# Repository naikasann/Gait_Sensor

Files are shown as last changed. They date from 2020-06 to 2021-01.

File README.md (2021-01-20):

# Gait_Sensor

歩容センサーの研究用リポジトリ
アーカイブ目的で運用している。

---

## 概要

健康促進などのための歩容を計測するデバイスを作成している。
その研究データを貯蓄するリポジトリ。

---

## ファイル構成

詳細は各フォルダー内に記載する。

- Gaitsensor --- 歩容センサーの計測を行うプログラム。BLE通信で左右の足のデータを計測し、Bluetooth classicで表示する。LPWA通信する機能などを追加予定。
- GaitSensor_Blynkdemo --- 歩容センサーのデモプログラム。スマートフォンアプリの[Blynk](https://blynk.io/)を用いて歩容の情報を表示するプログラムになっている。バグあり。
- GaitSensor_pintest --- 歩容センサーの動作確認をすることができるプログラム。
- GaitSensor_resource --- 歩容センサーを構築するための3Dプリンターのモデルをためておく場所
- LAWA --- LPWA通信(SensewayのLoRaWAN, Sigfox)をすることができるプログラム。

---

## 使用しているハードウェア

なるべく持続的に購入することができるリンクを添付しておく。

### ```マイコン部分```

- [ATOM Lite](https://www.switch-science.com/catalog/6262/)

今後はnRF52などのマイコンでの動作を行う予定。

### ```電池系```

- [リチウムイオンポリマー電池(3.7V、300mAh) DTP502035(PHR)](https://www.marutsu.co.jp/pc/i/1559500/)
- [LiPo Charger Plus(LiPo充電器) PRT-15217](https://www.marutsu.co.jp/pc/i/1558373/)

今後はボタン電池稼働を目指している。

### ```センサー```

センサーはetextileセンサーを用いている。

## 参加した学会

おそらく閲覧するにはいろいろ手続きが必要。

1. [CiNii 論文 -  インソール型歩容センサーのための歩容解析システムの構築](https://ci.nii.ac.jp/naid/170000182936/)
2. [研究会 開催プログラム - 2020-05-HIP-HCS-HI-SIGCE](https://www.ieice.org/ken/program/index.php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)

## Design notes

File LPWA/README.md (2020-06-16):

# LPWA

LPWAのテスト用プログラム置き場

---

## LoRa

LoRaのためのテストプログラム
温度と光センサーの値をLoRa通信する。
SenseWay Mission Connectのサービスを利用したもの。

### LoRa構成

``` 構成.
Sensor => Arduino(LoRaWAN Shield for Arduino付) =(LoRaWAN)> SenseWay Mission Connect
```

### 参考

1. 使用したサービス - [サービス概要 ｜ センスウェイ株式会社](https://www.senseway.net/service/network-service/)
2. 使用したデバイス - [LoRaWAN Shield for Arduino ｜ SenseWay Mission Connect LoRaWAN 対応製品ガイド](https://www.senseway.net/lorawan-service/item/device/lorawan-shield-for-arduino/)

---

## mqtt_subscribe

SenseWay Mission Connectからデータを受け取るためのプログラム
AWSやAzureなどでデータを吸出ししたくない時に運用することができる。

### mqtt_subscribe構成

``` 構成.
Arduino =(LoRaWAN)> SenseWay Mission Connect =(MQTT)> mqttsubscribe
```

詳細はファイル内のREADMEを参照

---

## Sigfox

Sigfoxをテストで送信してみるもの

### Sigfox構成

``` 構成.
マイコン =(UART)> Sigfoxbreakoutboard =(Sigfox)> sigfoxサービス
```

### 参考

1. 使用したデバイス - [Sigfox Breakout board BRKWS01 RC3 - スイッチサイエンス](https://www.switch-science.com/catalog/5373/)
2. プログラム参考 - [Sigfox Breakout Board (BRKWS01 RC3)の利用方法 - Qiita](https://qiita.com/ghibi/items/37154bad78d9bb57e335)
3. 参考 - [Sigfox Devkit（開発キット）を1年間の無償回線で利用する - Qiita](https://qiita.com/ghibi/items/5893923b44f1757294e9)
4. BackendSigfox(利用したサービス) - [BackendSigfox](https://backend.sigfox.com/auth/login)
5. 参考 - [Sigfox IoT Agency Platformで簡単ダッシュボード - すべてのモノが「つながる」新たな未来へ。IoTネットワーク「Sigfox」](https://www.kccs-iot.jp/20190121-technical/)

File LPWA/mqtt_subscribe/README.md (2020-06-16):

# mqtt subscriber for sensewaymisson connect

## 概要

LoRaのデータを管理するsenseway misson connectからのデータ受信をmqttプロトコルを用いて行う。
受信したデータは任意のデータのみ取り出し、csvにデータを保存する。

## システム構成

Arduino LoRaシールド =(LoRa)=> senseway mission connect =(mqtt)=> PC　=> csvfile

## ファイル構成

* mqtt_subscribe.py     ... mqttのサブスクライブが行える
* read_passward.py      ... sensewaymissonconnectのユーザー情報が書かれているテキストファイルからユーザー情報を読み取る
* pass_example.txt      ... pass.txtの書き方が書いてある
* Pipfile               ... pipのバージョン管理用
* data/data.csv         ... mqttsubscribeの出力先
* data/data_example.csv ... csvの出力例

## 実行環境

### python3.x系

各バージョン毎で動作確認等は行っていないが3.7.3で構築を行っているのでその近辺のバージョンは
確実に動く

### pip

#### * paho-mqtt

MQTTをpythonで動かすのに使用するライブラリ

#### ``` $pip install paho-mqtt ```

でインストールできる。

#### * pandas

データ解析を行うライブラリ
csv出力に使用する

#### ``` $pip install pandas ```

でインストールできる。

### memo

pipのインストールはproxy環境下では動作しません。

``` $pip install paho-mqtt --proxy=url:port```

で動作が行えます。

## 実行方法

pass_example.txtの中のように
* userid
* passward
* deveui
を記入したpass.txtを作成して

pythonファイルがあるディレクトリで

``` $python  mqtt_subscribe.py```

で実行することができる。

### 参考URL
1. [pythonでMQTT送受信 - Qiita](https://qiita.com/hsgucci/items/6461d8555ea1245ef6c2)
2. [pandas.DataFrameの構造とその作成方法 | note.nkmk.me](https://note.nkmk.me/python-pandas-dataframe-values-columns-index/)

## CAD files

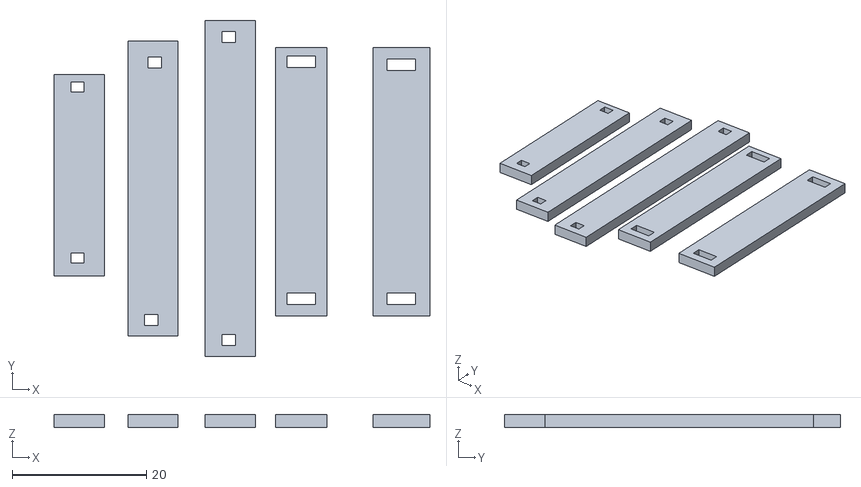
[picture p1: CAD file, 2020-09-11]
GaitSensor_resource/gaitsensor_base.stl
56.0 x 50.0 x 2.00

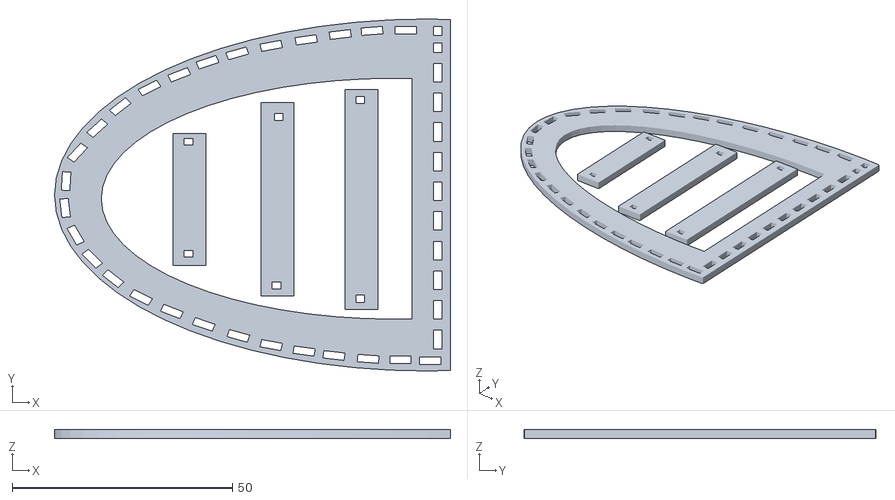
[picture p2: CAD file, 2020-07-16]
GaitSensor_resource/26cm_too.stl
90.0 x 80.0 x 2.00

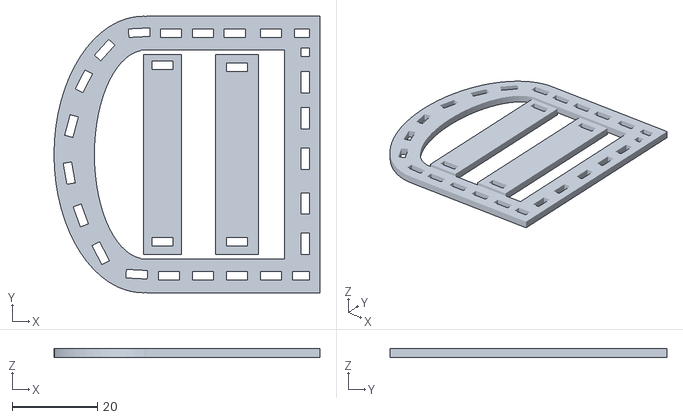
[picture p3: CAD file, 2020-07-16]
GaitSensor_resource/28cm_heel.stl
62.5 x 65.0 x 2.00

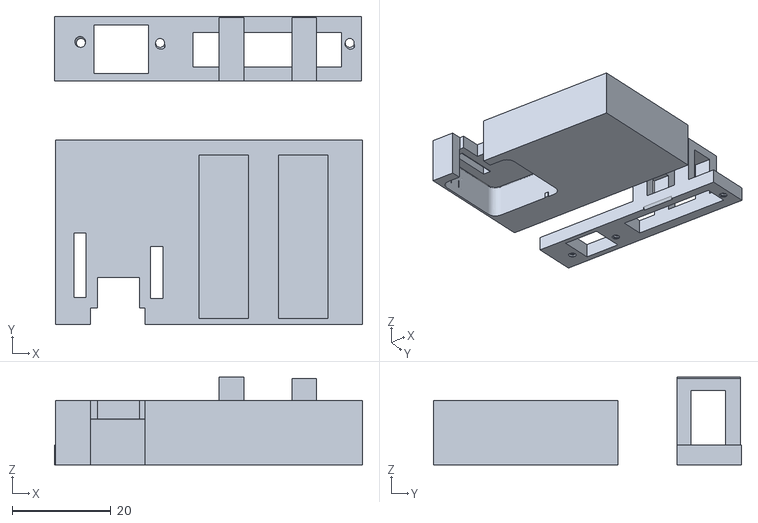
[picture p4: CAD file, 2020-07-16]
GaitSensor_resource/AtomLite_Battery_case_ver1_2.stl
62.2 x 62.2 x 17.8

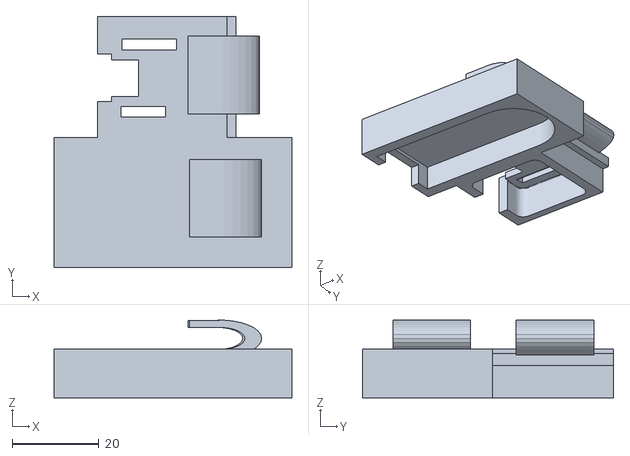
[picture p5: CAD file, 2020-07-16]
GaitSensor_resource/AtomLite_buttonbatt_case.stl
55.0 x 58.0 x 18.0

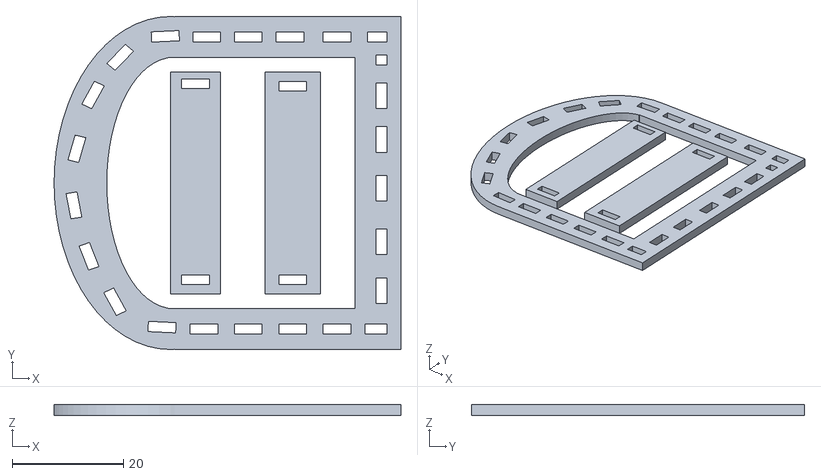
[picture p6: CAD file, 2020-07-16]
GaitSensor_resource/26cm_heel.stl
62.5 x 60.0 x 2.00

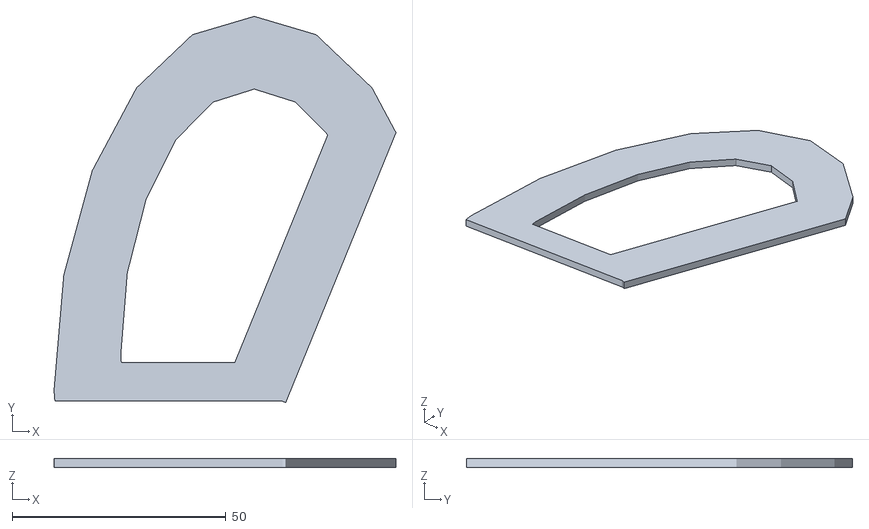
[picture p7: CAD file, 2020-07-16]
GaitSensor_resource/Ukiyubi_too_base.stl
80.0 x 90.3 x 2.00

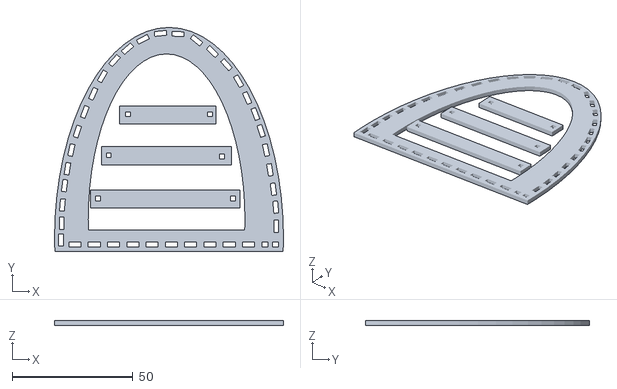
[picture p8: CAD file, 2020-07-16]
GaitSensor_resource/28cm_too.stl
95.0 x 93.0 x 2.00

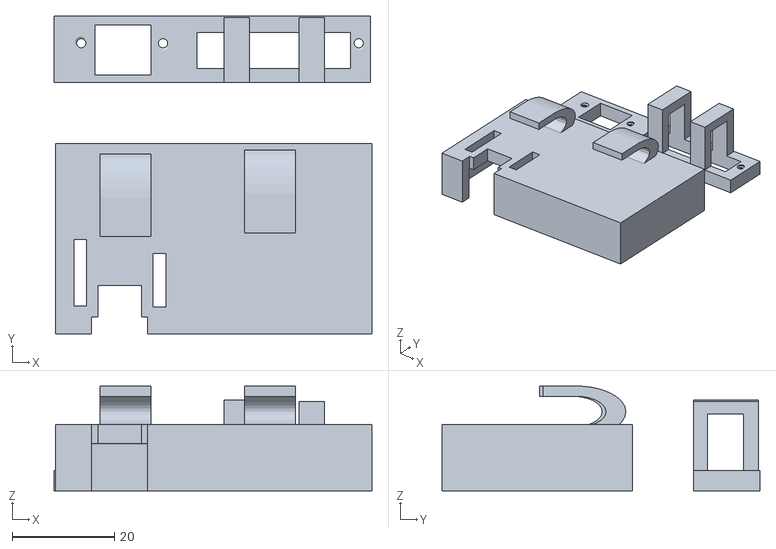
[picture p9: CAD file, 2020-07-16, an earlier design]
GaitSensor_resource/AtomLite_Battery_case_ver1_1.stl
62.2 x 62.2 x 20.5

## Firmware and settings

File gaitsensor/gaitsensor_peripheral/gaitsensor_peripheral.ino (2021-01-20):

// for microcomputer
#include "M5Atom.h"
// for BLE
#include <BLEDevice.h>
#include <BLEServer.h>
#include <BLE2902.h>
// for Bluetooth Serial function.(not BLE)
#include "BluetoothSerial.h"

// BLE service name
#define SERVER_NAME "Gait_sensor_peripheral"
// UUID defined (for BLE)
#define SERVICE_UUID           "28b0883b-7ec3-4b46-8f64-8559ae036e4e"
#define CHARACTERISTIC_UUID_TX "2049779d-88a9-403a-9c59-c7df79e1dd7c"
#define CHARACTERISTIC_UUID_RX "9348db8a-7c61-4c6e-b12d-643625993b84"
// For communication control
BLECharacteristic *pCharacteristicTX;   // characteristic for sending
BLECharacteristic *pCharacteristicRX;   // characteristic for receiving
bool deviceConnected = false;           // Device connections

// Define Bluetooth Serial variables.
#define SERIALBT_NAME "Gaitsensor_BT_Serial(2)"
BluetoothSerial SerialBT;

// for Terminal
#define SPI_SPEED 115200

// sensor pin defined
#define TOO_PIN 32
#define HEEL_PIN 26

// for LowPath filter.(N)
#define FILTER 1000

//移動平均用フィルター
#define GAIT_FILTER 10

//for Low path filter (Moving average filter)
int filter[FILTER] = {0};

// for BLE lag
// Number of transmissions and receptions to check for lag
#define SEND_AND_RECV_COUNT 10
//{左立脚期,左遊脚期,右立脚期,右遊脚期,左両脚支持期,右両脚支持期}
#define DATANUM 6

/*********************<     walking time value     >************************/
// send data.(send before time.The lag is calculated by comparing with the received time.)
int beforetime = 0;
// received time.
int aftertime = 0;
// Total measured data communication time
int sumMeasuretime = 0;
// Average measured data communication time
int aveMeasuretime = 0;

// before state (bool : Standing phase <= true, Swing period =< false)
bool beforestate;

// Walking data (stand time, swing time.)
int standtime = 0;
int swingtime = 0;
// other Walking data (stand time, swing time.)
int otherstandtime = 0;
int otherswingtime = 0;

//for Both feet support period
int maintime = 0;
bool mainon;
int subtime = 0;
bool subon;
int bothfoottime = 0;
int subbothfoottime = 0;

int walkingdata[DATANUM] = {0,0,0,0,0,0};

void input_data(int x, int n){
    if( x == 0 && n == 0 ){for(int i=0;i<=5;i++){walkingdata[i] = 0;}}
    else{walkingdata[x] = n;}
}

/*******************************************************************/

/*********************<     BLE callback function     >************************/
// connection and disconnection callback
class funcServerCallbacks: public BLEServerCallbacks{
    // on connect
    void onConnect(BLEServer* pServer){
        deviceConnected = true;
    }
    // on disconnect
    void onDisconnect(BLEServer* pServer){
        deviceConnected = false;
    }
};
// signal receive callback
class funcReceiveCallback: public BLECharacteristicCallbacks{
    void onWrite(BLECharacteristic *pCharacteristicRX){
        // Store received data in string type
        std::string rxValue = pCharacteristicRX->getValue();
        // Measured lag time (1 time measured)
        int measurelagtime;

        // We'll use a comparison operator to measure things like this.
        if(!strcmp(rxValue.c_str(), "100")){
            // Stores the execution time when received
            aftertime = millis();
            // Calculate the time required for communication.
            measurelagtime = aftertime - beforetime;
            sumMeasuretime += measurelagtime;
            // for debug
            Serial.print("Send and recv time : ");
            Serial.println(measurelagtime);
       //****************************************************************************************sub****************************************
        }else if(!strcmp(rxValue.c_str(), "1")){
            subon = true;
            subtime = millis();
            
            if(!mainon){
                    Serial.println("run!");
                    input_data(0,0);
                    input_data(1,swingtime);
            }
            
            otherswingtime = subtime - aftertime;
            Serial.println("            other swing time : " + String(otherswingtime));
            input_data(3,otherswingtime);
                 
        }else if(!strcmp(rxValue.c_str(), "0")){
            subon = false;
            aftertime = millis();
            otherstandtime = aftertime - subtime;
            if(otherstandtime > 50){
                Serial.println("            other stand time : " + String(otherstandtime));
                input_data(2,otherstandtime); 
                
                if(mainon){
                    subbothfoottime = aftertime - maintime;
                    Serial.println("            sub both foot on! time : " + String(subbothfoottime));
                    input_data(5,subbothfoottime);
                }
            }
        }
     //****************************************************************************************sub**************************************
    }
};

// Service Type Definition
void setBluetoothService(BLEService *pService){
    // Creating a Characteristic for Notify
    pCharacteristicTX = pService->createCharacteristic(
                      CHARACTERISTIC_UUID_TX,
                      BLECharacteristic::PROPERTY_NOTIFY
                    );
    pCharacteristicTX->addDescriptor(new BLE2902());

    // Create reception character sticks and set up a callback for incoming signals.
    pCharacteristicRX = pService->createCharacteristic(
                                           CHARACTERISTIC_UUID_RX,
                                           BLECharacteristic::PROPERTY_WRITE
                                         );
    pCharacteristicRX->setCallbacks(new funcReceiveCallback());
}
/******************************************************************************/
/*********************<        Setup (Prepare)        >************************/
void setup() {
    // for terminal
    Serial.begin(SPI_SPEED);
    // etextile pinMode setting
    pinMode(TOO_PIN,  INPUT_PULLUP);
    pinMode(HEEL_PIN, INPUT_PULLUP);
    // for M5Atom Lite
    M5.begin(true, false, true);

    // BLE init
    BLEDevice::init(SERVER_NAME);

    // Create server object & callback setting
    BLEServer *pServer = BLEDevice::createServer();
    pServer->setCallbacks(new funcServerCallbacks);

    // Create service object & prepare doing.
    BLEService *pService = pServer->createService(SERVICE_UUID);
    setBluetoothService(pService);

    // service start & advertising service uuid
    pService->start();
    BLEAdvertising *pAdvertising = pServer->getAdvertising();
    pAdvertising->addServiceUUID(SERVICE_UUID);
    pAdvertising->start();

    // Start a Bluetooth Serial.
    SerialBT.begin(SERIALBT_NAME);
    
    Serial.println("Waiting to connect...");
    // Wait for device to connect(Blinking LED on AtomLite)
    while(!deviceConnected){M5.dis.drawpix(0, 0x0000f0);delay(1000);M5.dis.drawpix(0, 0x000000);delay(200);}
    // Now that the connection is complete, turn on the white LED and start the measurement.
    M5.dis.drawpix(0, 0x707070);
    Serial.println("connection!");
    delay(1000);

    // Start measuring lag
    Serial.println("Start measuring lag!");
    for(int i = 0;i < SEND_AND_RECV_COUNT; i++){
        // send count data.Give the first time of lag measurement. for debug
        Serial.println("send data :" + String(i));
        // set senddata. this is test send count.
        pCharacteristicTX->setValue(i);
        pCharacteristicTX->notify();
        // data send (checking send before time.)
        beforetime = millis();
        delay(500);
    }
    Serial.println("The lag measurement is complete.");
    // Calculation
    aveMeasuretime = sumMeasuretime / SEND_AND_RECV_COUNT;
    // for debug
    Serial.print("Total time when communication was performed : ");
    Serial.println(sumMeasuretime);
    Serial.print("Total average time :");
    Serial.println(aveMeasuretime);
    Serial.println("Analyzes gait information");

    delay(aveMeasuretime);
    Serial.println(3);
    delay(1000);
    Serial.println(2);
    delay(1000);
    Serial.println(1);
    delay(1000);
    beforetime = millis(); aftertime = millis();
    maintime = millis(); subtime = millis();
}
/******************************************************************************/
/*********************<          Main sequence        >************************/
void loop() {
    float ave = 0.0;
    // do Low path filter (Moving average filter)
    for(int i = FILTER - 1; i > 0; i--) filter[i] = filter[i - 1];
    if((digitalRead(TOO_PIN) == LOW)||(digitalRead(HEEL_PIN) == LOW)) filter[0] = 1;
    else  filter[0] = 0;
    // decide walking state
    for(int i = 0; i < FILTER; i++) ave += filter[i];
    ave = (float)ave / FILTER;

    if(ave >= 0.7){       //左足が地に着いた
        if(!beforestate){
            M5.dis.drawpix(0, 0x000070);
            mainon = true;
            maintime = millis();
            if(!subon){
                    Serial.println("run!");
                    input_data(0,0);
                    input_data(3,otherswingtime);
            }
            swingtime = maintime - beforetime;
            Serial.println("swingtime : " + String(swingtime));
            input_data(1,swingtime);
            
            SerialBT.printf("%d,%d,%d,%d,%d,%d\n",walkingdata[0],walkingdata[1],walkingdata[2],walkingdata[3],walkingdata[4],walkingdata[5]);
            Serial.printf("   %d,%d,%d,%d,%d,%d\n",walkingdata[0],walkingdata[1],walkingdata[2],walkingdata[3],walkingdata[4],walkingdata[5]);
            input_data(0,0); //初期化
        }
        beforestate = true;
    }else{
        if(beforestate){
            M5.dis.drawpix(0, 0x700000);
            mainon = false;
            beforetime = millis();
            standtime = beforetime - maintime;
            if(standtime > 50){
                Serial.println("standtime : " + String(standtime));
                input_data(0,standtime);
                
                if(subon){
                    bothfoottime = beforetime - subtime;
                    Serial.println("main both foot on! time : " + String(bothfoottime));
                    input_data(4,bothfoottime);
                }
            }
        }
        beforestate = false;
    }
}

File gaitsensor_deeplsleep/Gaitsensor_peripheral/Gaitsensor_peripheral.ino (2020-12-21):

#include "M5Atom.h"

#include <Ticker.h>

#include <BLEDevice.h>
#include <BLEServer.h>
#include <BLE2902.h>
#include "BluetoothSerial.h"

// BLE service name
#define SERVER_NAME "Gait_sensor_central"
// UUID defined (for BLE)
#define SERVICE_UUID           "28b0883b-7ec3-4b46-8f64-8559ae036e4e"
#define CHARACTERISTIC_UUID_TX "2049779d-88a9-403a-9c59-c7df79e1dd7c"
#define CHARACTERISTIC_UUID_RX "9348db8a-7c61-4c6e-b12d-643625993b84"
// For communication control
BLECharacteristic *pCharacteristicTX;   // characteristic for sending
BLECharacteristic *pCharacteristicRX;   // characteristic for receiving
bool deviceConnected = false;           // Device connections

// for Terminal
#define SPI_SPEED 115200

// sensor pin defined
#define TOE_PIN 32
#define HEEL_PIN 26
// for LowPath filter.(N)
#define FILTER 1000
// Moving average filter threshold
#define FILTER_THRESHOLD 0.7
int toe_filter[FILTER] = {0};
int heel_filter[FILTER] = {0};

// Where to temporarily store the measurements when
// memo : main => this micro computer. sub => BLE communication partner microcomputer.
int main_bufftime = 0;
int sub_bufftime = 0;
// One previous walking state (one foot)
// before state (int : heel => 0, stand => 1, toe => 2, swing => 3.)
int main_beforestate = 0;
int sub_beforestate = 0;
// for both foot time.
// on => true, off => false.
bool main_foot_state = false;
bool sub_foot_state = false;
// for bothfoottime buffer valiable
int main_foot_bufftime = 0;
int sub_foot_bufftime = 0;

// Number of gait parameters to be retrieved (no need to change!)
#define WALK_STATE_COUNT 10
// [right heel, stand, toe, swing, left heel, stand, toe, swing, bothtime1, bothtime2]
int walkstime[WALK_STATE_COUNT] = {0};
// Information on Steps for Deep Sleep.
int mainsteps = 0;
int substeps = 0;

// Declaring a timer interrupt handler to check for the working.
Ticker movechecker;
bool isMove = false;
// Setting the interval to check the operation(sec)
#define MOVECHECKTIME 2
// run checker.
#define RUN_THRESHHOLD 4
int run_threshhold = 0;
// Set the time to do deep sleep (sec)
#define DEEPSLEEPTIME 30
// Set the number of gait cycles to perform a deep sleep
#define DEEPSLEEPSTEPS 10

// function : Assign the value to the specified index of walkstime.
void set_walktime(int index, int inputdata){
    walkstime[index] = inputdata;
}

// function : Clean output of the values stored in walkstime
void print_walktime(){
    for(int i = 0; i < WALK_STATE_COUNT; i++){
        Serial.print(walkstime[i]);
        Serial.print(",");
    }
    Serial.println("");
}

void doSleep(bool issend){
    M5.dis.drawpix(0, 0xf0f0f0);
    Serial.println("sleep");
    if (issend){
        // Put out the support so that the other leg starts to sleep deep.
        int sendvalue = 2525;
        pCharacteristicTX->setValue(sendvalue);
        pCharacteristicTX->notify();
    }
    // set deepsleep.
    esp_sleep_enable_timer_wakeup(DEEPSLEEPTIME * 1000 * 1000);
    esp_deep_sleep_start();
}

// function : Operate at regular intervals. If not moving, perform a deep sleep on both feet.
void move_check() {
    Serial.println("movecheck");
    if(isMove){
        isMove = false;
    }else{
        doSleep(true);
    }
}

// connection and disconnection callback (Assign a bool value to the device's connection status)
class funcServerCallbacks: public BLEServerCallbacks{
    void onConnect(BLEServer* pServer){
        deviceConnected = true;
    }
    void onDisconnect(BLEServer* pServer){
        deviceConnected = false;
    }
};

// signal receive callback
class funcReceiveCallback: public BLECharacteristicCallbacks{
    void onWrite(BLECharacteristic *pCharacteristicRX){
        int measured_val = 0;
        int both_measured = 0;
        // Store received data in string type
        std::string rxValue = pCharacteristicRX->getValue();

        // We'll use a comparison operator to measure things like this.
        // other foot state : heel.
        if(!strcmp(rxValue.c_str(), "0")){
            // toe => off, heel => on.
            measured_val = millis() - sub_bufftime;
            sub_bufftime = millis();
            substeps++;
            // swing time setting.
            set_walktime(7, measured_val);
            sub_foot_bufftime = millis();
            sub_foot_state = true;
        }
        // other foot state : stand.
        if(!strcmp(rxValue.c_str(), "1")){
            // toe => on, heel => on.
            measured_val = millis() - sub_bufftime;
            sub_bufftime = millis();
            // heel time setting.
            set_walktime(4, measured_val);
            sub_foot_state = true;
        }
        // other foot state : toe.
        if(!strcmp(rxValue.c_str(), "2")){
            measured_val = millis() - sub_bufftime;
            sub_bufftime = millis();
            // stand time setting.
            set_walktime(5, measured_val);
            sub_foot_state = true;
        }
        // other foot state : swing.
        if(!strcmp(rxValue.c_str(), "3")){
            // toe => off, heel => off.
            measured_val = millis() - sub_bufftime;
            sub_bufftime = millis();
            // toe time setting.
            set_walktime(6, measured_val);
            if(main_foot_state){
                both_measured = sub_bufftime - main_foot_bufftime;
                set_walktime(9, both_measured);
            }else{
                //Serial.println("RUN!!");
                set_walktime(9, 0);
            }
            sub_foot_state = false;
        }

        // The other leg sent a deep sleep command, and we followed that command to perform a deep sleep.
        if(!strcmp(rxValue.c_str(), "2525")){
            // set deepsleep.
            doSleep(false);
        }
    }
};

// Service Type Definition
void setBluetoothService(BLEService *pService){
    // Creating a Characteristic for Notify
    pCharacteristicTX = pService->createCharacteristic(
                      CHARACTERISTIC_UUID_TX,
                      BLECharacteristic::PROPERTY_NOTIFY
                    );
    pCharacteristicTX->addDescriptor(new BLE2902());

    // Create reception character sticks and set up a callback for incoming signals.
    pCharacteristicRX = pService->createCharacteristic(
                                           CHARACTERISTIC_UUID_RX,
                                           BLECharacteristic::PROPERTY_WRITE
                                         );
    pCharacteristicRX->setCallbacks(new funcReceiveCallback());
}
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

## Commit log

2020-06-16 :sparkles: LoRaプログラムの追加
2020-06-16 :sparkles: Sigfoxプログラムの追加
2020-06-16 :see_no_evil: gitignoreの追加
2020-06-16 :sparkles: MQTT_subscribeプログラムの追加
    Sensewaymissionconnect用
2020-06-16 :pencil: LPWAプログラム置き場用のREADMEの追加
2020-06-16 :pencil: MQTTsubscribeのREADMEの追加
2020-06-16 :construction: GaitsensorのPeripheral側の追加
2020-06-16 :wrench: 設定ファイルの例の追加
2020-06-30 :construction: 以前作成した計測プログラムを追加
2020-07-16 :sparkles: インソール用の3Dプリンターモデルの追加
    [26cm_heel.stl, 26cm_too.stl, 28cm_heel.stl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]
2020-07-16 :sparkles: pinテスト用のプログラムの追加
2020-07-16 :sparkles: BluetoothSerial用のmacアドレス確認用プログラムの追加
2020-07-16 :sparkles: デモを実施した際のプログラム
2020-07-22 :truck: ファイルの移動
2020-07-22 :construction: デモ用プログラムの作成
    ほぼ完成
    あとは情報をもう少し出すように
2020-07-29 :construction:Blynkデモの 立脚期、両足支持期などの計測を追加
2020-09-08 :bug: Blynkデモの変数などのバグ修正
    動作確認済み
2020-09-08 :pencil: READMEの更新
2020-09-11 :sparkles: ベースの補助板のみのモデル追加
    [gaitsensor_base.stl]
2020-12-11 :wrench: 歩容センサーのピン番号の変更
2020-12-21 :fire: 立脚期と遊脚期を計測するプログラムの削除
    使用しないため
2020-12-21 :sparkles: 立脚期、遊脚期の計測プログラムの追加
    初期、中期、終期を分けて表示する。
2020-12-21 :sparkles: 歩行検知プログラムの追加
    歩行か静止状態か確認しながら動作する
    また走っている場合も省電力化する
2021-01-20 2stateの計測プログラムの追加
